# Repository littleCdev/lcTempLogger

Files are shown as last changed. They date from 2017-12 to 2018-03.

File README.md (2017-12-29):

# lcTempLogger
lcTemplogger is a simple ESP8266 temperature-logger using the DS18B22 onewire sensors to feed iot-databases like emoncms / thinkspeak / etc.
You can flash the software onto the ESP8266 without editing the code, setting up the wifi is done via a webinterface.

## Sleep mode
the used ESP8266-01 requires the GPIO 16 wired to RST to wake up from deepsleep mode. if you don't do this the ESP will 
never wake up on itself.
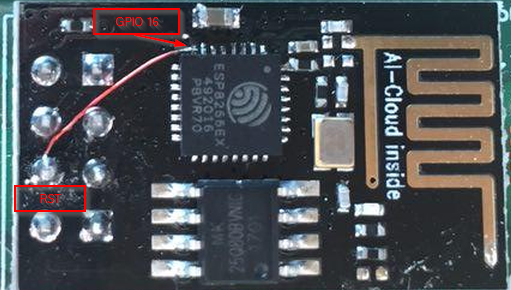
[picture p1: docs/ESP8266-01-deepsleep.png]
ESP8266-01 Deepsleep


## Powersaving
To not drain the batteries too much, the ESP will shutdown after 5 minutes of inactivity in configuration mode, you can simply wake it up again by pressing the reset button.

I suggest to remove the red power-led from the board. This can be done using a soldering iron or just break it out carefully.

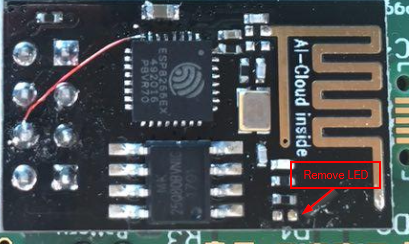
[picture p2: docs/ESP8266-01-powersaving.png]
ESP8266-01 Powersaving ESP8266-01 remove power-led


## Building
Building and flashing is done via the Arduino-IDE

add the ESP to your IDE following this guide 
https://github.com/esp8266/Arduino#installing-with-boards-manager

All other required libraries like onewire and the DS18B22 are included into the sketch. Go to arduino/lcTempLogger/ and open lcTempLogger.ino and hit the uploadbutton

Settings
* Board "Generic ESP8266 Module"
* Flash Mode "DIO"
* Flash Frequency "40MHz"
* CPU Frequency "80MHz"
* Flash Size "1M (512k SPIFFS)"
* Debug port "Disabled"
* Debug Level "None"
* Reset Method "ck"
* Upload Speed "115200"

#### uploading the sketchdata
Use the [esp8266fs-plugin](https://github.com/esp8266/arduino-esp8266fs-plugin) to upload the data into the spiffs.

After including the plugin into the IDE you can simply hit tool->ESP8266 Sketch Data Upload 

## Configuring
If done everything correctly you should be able to find a wifi called "LC-ESP8266-XXXXXXXX",
 connect to it with the password "12345678" (yes, i know it is insecure, but the wifi will be on for configuration only) 
and open 192.168.1.4 in a webbrowser. Select your Network, enter the password and hit "Save" after waiting a bit 
(the ESP is sometimes slow with connecting) until the Wifistatus changes to "connected".
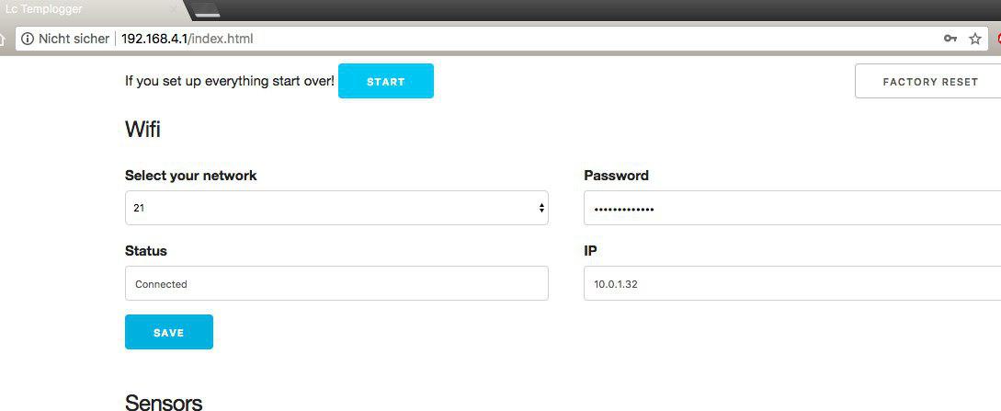
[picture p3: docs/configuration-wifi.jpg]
Wifi configuration

#### API's
Under "API's" you are able to select a preset for emoncms or thinkspeak, just replace your apikey with the placesholder.
I you want to use another API just add the URL, the method (Post or Get) and set the headers and Postdata.
Hit save and try making a testcall under "Test API", you will see the response in the textbox below the testbutton.

If everything works go to the top of the page and hit "Start" to set the ESP to deepsleep.

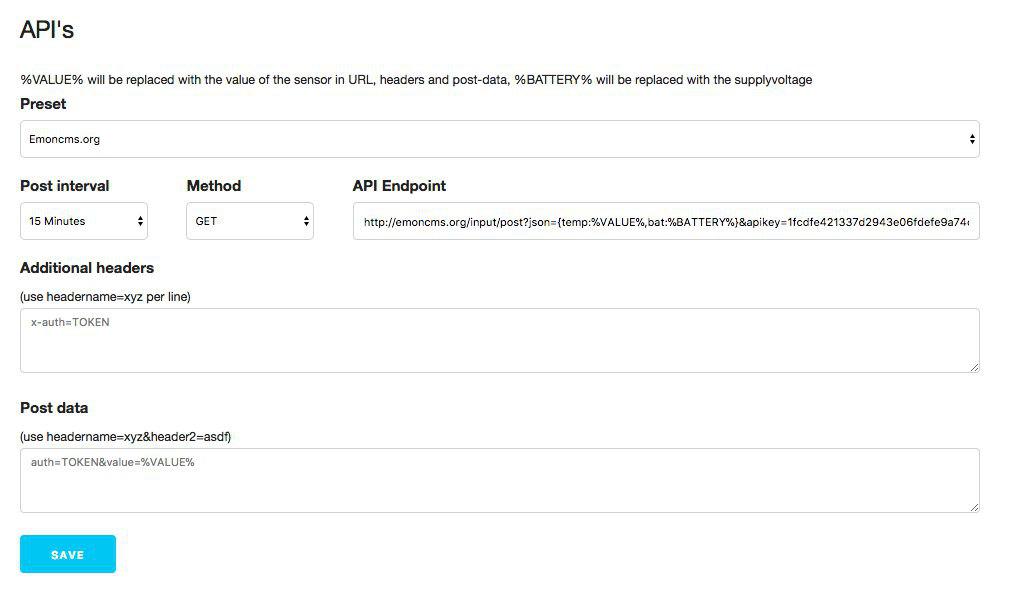
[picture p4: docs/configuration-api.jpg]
API configuration

#### Aborting deepsleep
if you want to wake up the ESP to change settings like API, wifi or whatever press the reset-button, after that you have 2 seconds 
to press the "Set" button once and the ESP will wake up with the accesspoint enabled for configuring. (You need to start the deepsleep again via the webinterface)

## Boards
the board is designed to work with normal AAA-batteries or a 3.7V Lipo including a simple charging circuit using the TP4056 and a MCP1700 as voltageregulator.
You can find the eagle-files in eagle/ (eagle version 7.5)
Boards can be easily ordered at [aisler.net](https://aisler.net/littleCdev/my-project-repository/esp8266-templogger)

Example boards from aisler, left: AAA-battery powered, right using a 3.7V 500mAh lipo battery with charger
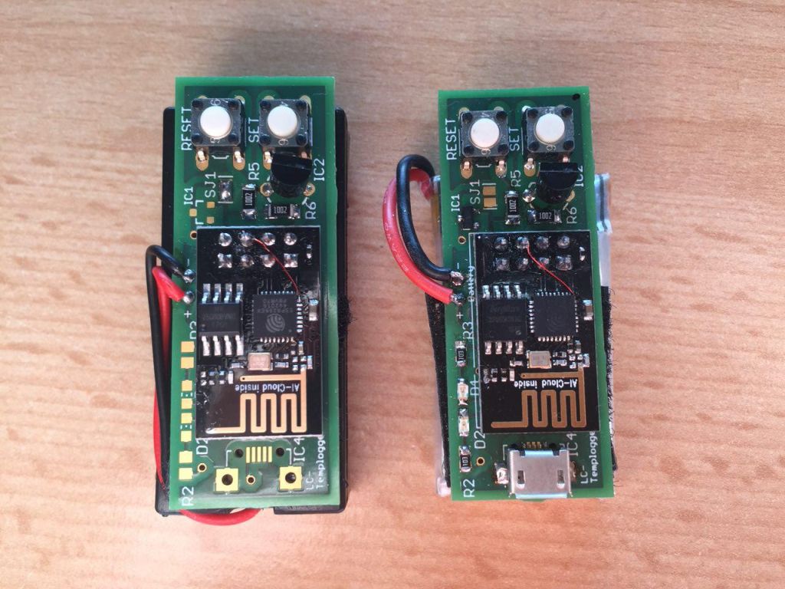
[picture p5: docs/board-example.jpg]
Example boards from aisler


>For AAA-battery powered boards set SJ1 and **don't** place following components 
* IC1 
* IC3
* R1
* R2
* R3
* D1
* D2

# Licence MIT
Copyright 2017 Matthias Böck

Permission is hereby granted, free of charge, to any person obtaining a copy of this software and associated documentation files (the "Software"), to deal in the Software without restriction, including without limitation the rights to use, copy, modify, merge, publish, distribute, sublicense, and/or sell copies of the Software, and to permit persons to whom the Software is furnished to do so, subject to the following conditions:

The above copyright notice and this permission notice shall be included in all copies or substantial portions of the Software.

THE SOFTWARE IS PROVIDED "AS IS", WITHOUT WARRANTY OF ANY KIND, EXPRESS OR IMPLIED, INCLUDING BUT NOT LIMITED TO THE WARRANTIES OF MERCHANTABILITY, FITNESS FOR A PARTICULAR PURPOSE AND NONINFRINGEMENT. IN NO EVENT SHALL THE AUTHORS OR COPYRIGHT HOLDERS BE LIABLE FOR ANY CLAIM, DAMAGES OR OTHER LIABILITY, WHETHER IN AN ACTION OF CONTRACT, TORT OR OTHERWISE, ARISING FROM, OUT OF OR IN CONNECTION WITH THE SOFTWARE OR THE USE OR OTHER DEALINGS IN THE SOFTWARE.

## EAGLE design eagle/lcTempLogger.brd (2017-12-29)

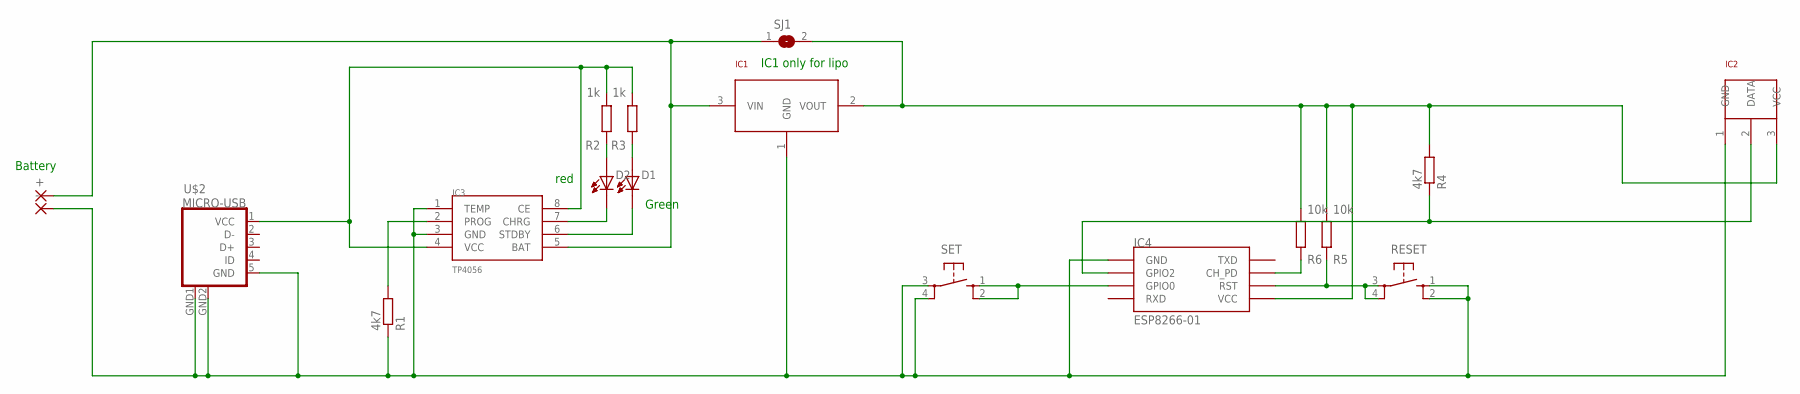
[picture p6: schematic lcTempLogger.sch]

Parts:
+: 1,6/0,8
-: 1,6/0,8
D1, D2: LED-0805; CHIPLED_0805
IC1: MCP1700; SOT-23
IC2: DS18B20TO-92; TO-92
IC3: TP4056; SOP-8
IC4: ESP8266-01; ESP01
R1, R4: 4k7; R1206
R2, R3: 1k; R0805
R5, R6: 10k; R1206
RESET: 10-XX; B3F-10XX
SET: 10-XX; B3F-10XX
SJ1: SJ
U$2: MICRO-USB

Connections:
3V: IC1.2 (VOUT), IC2.3 (VCC), IC4.VCC, R4.2, R5.2, R6.2, SJ1.2
5V_USB: IC3.4 (VCC), IC3.8 (CE), R2.2, R3.2, U$2.1 (VCC)
GND: -.1, IC1.1 (GND), IC2.1 (GND), IC3.1 (TEMP), IC3.3 (GND), IC4.GND, R1.1, RESET.1, RESET.2, SET.3, SET.4, U$2.5 (GND), U$2.GND1 (GND), U$2.GND2 (GND)
unnamed: D2.C (K), IC3.7 (CHRG)
unnamed: IC2.2 (DATA), IC4.GPIO2, R4.1
unnamed: +.1, IC1.3 (VIN), IC3.5 (BAT), SJ1.1
unnamed: IC4.GPIO0, SET.1, SET.2
unnamed: D1.C (K), IC3.6 (STDBY)
unnamed: IC3.2 (PROG), R1.2
unnamed: D2.A, R2.1
unnamed: D1.A, R3.1
unnamed: IC4.RST, R5.1, RESET.3, RESET.4
unnamed: IC4.CH_PD, R6.1

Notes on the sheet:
Battery
IC1 only for lipo
Green
red

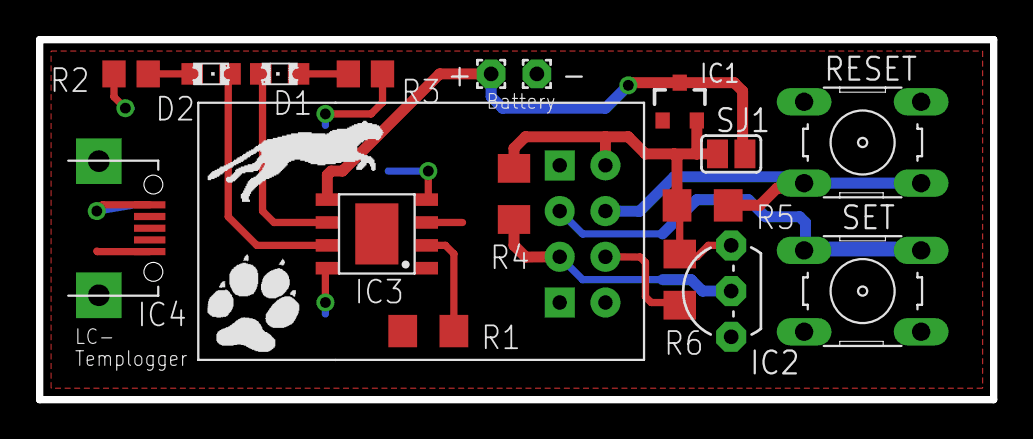
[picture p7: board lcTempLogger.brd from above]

Board: 2 copper layers, 53.0 x 20.0 mm, 20 parts (0 on the bottom side), 13 nets.

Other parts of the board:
U$1: LOGO-21-SMALL-PAW
U$3: LOGO-21-MIDDLE-CHEETAH

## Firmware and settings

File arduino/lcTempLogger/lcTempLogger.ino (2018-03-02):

#include <ESP8266WiFi.h>
#include <WiFiClient.h>
#include <ESP8266WebServer.h>
#include <ESP8266mDNS.h>
#include <ESP8266HTTPClient.h>
#include <DNSServer.h>
#include "OneWire.h"
#include "DallasTemperature.h"
#include "FS.h"

#define HOSTNAME            "ESP8622"
#define APDEFAULTNAME       "LC-ESP8266"    // mac will be added to the end
#define APDEFAULTPW         "12345678"
#define ONE_WIRE_BUS        2               // GPIO
#define INACIVITY_RESET     g_ulInactivTime = millis();Serial.println("reset inactivity");
/*
 * https://thingspeak.com/
 * https://github.com/nothans/ESP8266/blob/master/examples/A0_to_ThingSpeak.ino
 * 
 * https://io.adafruit.com/
 *
 * https://emoncms.org/
 */

/*
 * Prototypes
 */
void sendFile(String sFile = "");
void goToSleep();
void shutdown();
void factoryReset();
bool saveStringToFile(String sContent,String sName);
String readStringFromFile(String sName);
void getDefaultApName(char *sString);
void saveApiSettings();
void getApiSettings();
String saveWifiSettings();
void handleNotFound();
void getNetworkStatus();
void setupWebserver();
void checkForDeepSleep();

/*
 * Globals
 */
// IP-Addresses for accesspoint
IPAddress g_apIP(192, 168, 4, 1);
IPAddress g_netMsk(255, 255, 255, 0);

// Web-server
ESP8266WebServer server(80);

// DNS-server
const byte DNS_PORT = 53;
DNSServer dnsServer;

// 1wire sensor (DS18B20)
OneWire oneWire(ONE_WIRE_BUS);
DallasTemperature sensors(&oneWire);

// measure supplyvoltage
ADC_MODE(ADC_VCC);

// timeout for wifi-connect
unsigned long g_ulStartTime;
unsigned long g_ulInactivTime;
// 
int g_bTryConnect = false;
int g_bConnectCanel = false;
// don't send Message to client
int g_bDeepSleep = false;
void goToSleep(){
  if(!g_bDeepSleep){
    // don't write the file every time
    saveStringToFile("1","deepsleep");
    server.send(200,"text/json","see ya!");
  }
  
  Serial.println("good night!");
  
  String sSleepTime = readStringFromFile("api.interval");
  int iSleepTime = sSleepTime.toInt();
  // 1000000 == 1s 
  ESP.deepSleep(1000000*60*iSleepTime, WAKE_RF_DEFAULT);
  delay(100);
}

void shutdown(){
  Serial.println("shutdown");
  ESP.deepSleep(999999999*999999999*999999999U, WAKE_RF_DEFAULT);
  delay(100);
}


void factoryReset(){
  SPIFFS.remove("api.method");
  SPIFFS.remove("api.endpoint");
  SPIFFS.remove("api.headers");
  SPIFFS.remove("api.post");
  SPIFFS.remove("api.interval");
  
  SPIFFS.remove("wifi.name");
  SPIFFS.remove("wifi.pw");
  SPIFFS.remove("deepsleep");

   ESP.eraseConfig();
   ESP.restart();  
}

bool setApiRequest(){
  String sValue = "";

  if(WiFi.status() != WL_CONNECTED){
    if(!g_bDeepSleep)
      server.send(200,"text/plain","wifi not connected!");

    Serial.println("wifi not connected!");
    return false;
  }

  // 85°C == Failture
  while(sValue == "" || sValue.startsWith("85.0")){
    sensors.requestTemperatures();
    delay(10);
    sValue = sensors.getTempCByIndex(0);
  }
  float fVcc=ESP.getVcc()/1024.00f;
  String sVcc = String(fVcc);
  
  String sEndPoint = readStringFromFile("api.endpoint");

  String sMethod = readStringFromFile("api.method");

  sMethod.toLowerCase();
  
  sEndPoint.replace("%VALUE%",sValue);
  sEndPoint.replace("%BATTERY%",sVcc);
  Serial.println("endpoint: "+sEndPoint);
  
  
  HTTPClient http;
  http.begin(sEndPoint);

  // add headers
  File fHeaders = SPIFFS.open("api.headers","r");
  if(fHeaders){
    String sLine = "";
    while(sLine = fHeaders.readStringUntil('\n')){
      
      if(sLine.length() == 0)
        break;

      sLine.replace("%VALUE%",sValue);
      sLine.replace("%BATTERY%",sVcc);
      Serial.println("Read line from api.headers: "+sLine);

      for (int i = 0; i < sLine.length(); i++) {
        if (sLine.substring(i, i+1) == "=") {
          String sKey = sLine.substring(0, i);
          String sValue = sLine.substring(i+1);

          Serial.println("Found header: "+sKey+" - "+sValue);
          http.addHeader(sKey,sValue);
          i=sLine.length();
        }
      }
    }
  }else{
    Serial.println("no headers to add");
  }

  
  int iHttpCode = -1;
  if(sMethod == "post"){
    
    http.addHeader("Content-Type", "application/x-www-form-urlencoded");
    char acPayload[200] = {};
    String sPayload = "";
    File fPostData = SPIFFS.open("api.post","r");
    if(!fPostData){
      Serial.println("failed to open api.method");
    }else{
          while (fPostData.available()){
            sPayload += char(fPostData.read());
          }
          fPostData.close();
          
          sPayload.replace("%VALUE%",sValue);
          sPayload.replace("%BATTERY%",sVcc);
          
  }
    
    Serial.println("POST");
//    iHttpCode = http.POST((uint8_t*)acPayload,sizeof(acPayload));
    iHttpCode = http.POST(sPayload);
  }else{
    Serial.println("GET");
    iHttpCode = http.GET();
  }
  
  Serial.println("http-code: ");
  Serial.println(iHttpCode);

  if(!g_bDeepSleep)
    server.send(200,"text/plain",http.getString());
  
  http.end();
  return true;
}

bool saveStringToFile(String sContent,String sName){
  File fName = SPIFFS.open(sName,"w");
  if(!fName){
    Serial.println("failed to open "+sName);
     return false;
  }
  fName.print(sContent);
  fName.close();
  return true;
}
String readStringFromFile(String sName){
  if(!SPIFFS.exists(sName)){
    return "";
  }
  
  File fFile = SPIFFS.open(sName,"r");
  if(!fFile){
    Serial.println("failed to open "+sName);
    return "";
  }

  String sRead = fFile.readStringUntil('\n');
  fFile.close();

  return sRead;
}
void getDefaultApName(char *sString){
  byte mac[6] = {0};
  WiFi.macAddress(mac);
  snprintf(sString,100,"%s-%02x%02x%02x%02x%02x%02x",APDEFAULTNAME,mac[0],mac[1],mac[2],mac[3],mac[4],mac[5]);
}

void saveApiSettings(){
  for (uint8_t i=0; i<server.args(); i++){
    if(server.argName(i) == "ApiMethod"){
      saveStringToFile(server.arg(i),"api.method");
    }
    if(server.argName(i) == "ApiEndpoint"){
      saveStringToFile(server.arg(i),"api.endpoint");
    }
    if(server.argName(i) == "ApiHeaders"){
      saveStringToFile(server.arg(i),"api.headers");
    }
    if(server.argName(i) == "ApiPost"){
      saveStringToFile(server.arg(i),"api.post");
    }
    if(server.argName(i) == "ApiInterval"){
      saveStringToFile(server.arg(i),"api.interval");
    }
  }
}

void getApiSettings(){
  String sMessage = "{\"method\":\"";
  sMessage += readStringFromFile("api.method");
  sMessage += "\",\"endpoint\":\"";
  sMessage += readStringFromFile("api.endpoint");
  sMessage += "\",\"headers\":\"";
  sMessage += readStringFromFile("api.headers");
  sMessage += "\",\"post\":\"";
  sMessage += readStringFromFile("api.post");
  sMessage += "\",\"interval\":\"";
  sMessage += readStringFromFile("api.interval");
  sMessage += "\"}";
  server.send(200,"text/json",sMessage);
}

void WifiTryConnect(){
  String sPasswd = "";
  char charBufsPasswd[50];
  String sWifiName = "";
  char charBufsWifiName[50];

  sWifiName = readStringFromFile("wifi.name");
  sPasswd = readStringFromFile("wifi.pw");
  
  Serial.println("got networkname: "+sWifiName+" and password: "+sPasswd);
  // convert "String" into char[]... i hate c++
  sPasswd.toCharArray(charBufsPasswd, 50);
  sWifiName.toCharArray(charBufsWifiName, 50);

  WiFi.begin(charBufsWifiName,charBufsPasswd);
  g_bConnectCanel = false;
}

String saveWifiSettings(){
  String sPasswd = "";
  String sName = "";
  
  for (uint8_t i=0; i<server.args(); i++){
    if(server.argName(i) == "WifiName"){
      sName = server.arg(i);
    }
   if(server.argName(i) == "WifiPass"){
      sPasswd = server.arg(i);
    }
  }

  if(sName.length() == 0){
    return "Wifiname can't be empty!";
  }

  // save settings to files
  if(!saveStringToFile(sName,"wifi.name")){
     Serial.println("failed to save wifi.name");
     return"failed to save wifi.name" ;
  }
  Serial.println("saved wifi.name");
  
  if(!saveStringToFile(sPasswd,"wifi.pw")){
     Serial.print("failed to save wifi.pw");
     return"failed to save wifi.pw" ;
  }
  Serial.println("saved wifi.pw");

  g_bTryConnect = 1;
  
  return "Saved";
}


void handleNotFound(){
  INACIVITY_RESET

  if(SPIFFS.exists(server.uri())){
    sendFile();
    return;
  }
  if(server.uri()=="/"){
    sendFile("/index.html");
    return;
  }
    
  String message = "File Not Found\n\n";
  message += "URI: ";
  message += server.uri();
  message += "\nMethod: ";
  message += (server.method() == HTTP_GET)?"GET":"POST";
  message += "\nArguments: ";
  message += server.args();
  message += "\n";
  for (uint8_t i=0; i<server.args(); i++){
    message += " " + server.argName(i) + ": " + server.arg(i) + "\n";
  }
  server.send(404, "text/plain", message);
}

void sendFile(String sFile){
  String sFileToSend = sFile;
  if(sFile.length() == 0)
    sFileToSend = server.uri();
    
  Serial.println("trying to send file: "+sFileToSend);
  File f = SPIFFS.open(sFileToSend,"r");
  if(!f){
    Serial.println("failed to open "+sFileToSend);
    return;
  }

  if(sFileToSend.endsWith("html")){
    server.streamFile(f,"text/html");     
  }else if(sFileToSend.endsWith("css")){
    server.streamFile(f,"text/css");    
  }else if(sFileToSend.endsWith("js")){
    server.streamFile(f,"text/javascript");    
  }
  f.close();
}
void getNetworkStatus(){
  IPAddress ip = WiFi.localIP();
  String sMessage = "{\"state\":\"";

  switch(WiFi.status())
  {
    case WL_NO_SHIELD: sMessage+= "No Wifi shiled";  break;
    case WL_IDLE_STATUS: sMessage+= "Idle";  break;
    case WL_NO_SSID_AVAIL: sMessage+= "SSID not available";  break;
    case WL_SCAN_COMPLETED: sMessage+= "Scan done";  break;
    case WL_CONNECTED: sMessage+= "Connected";  break;
    case WL_CONNECT_FAILED: sMessage+= "Connection failed";  break;
    case WL_CONNECTION_LOST: sMessage+= "Connected lost";  break;
    case WL_DISCONNECTED: sMessage+= "Not connected";  break;
  }
  sMessage+="\",\"ip\":\"";
  for(int i=0;i<4;i++){
    sMessage+=ip[i];
    if(i<3)
      sMessage+="."; 
  }
  sMessage+="\"}";
  server.send(200,"text/json",sMessage);
}
void getSensor(){
  String sMessage = "{\"sensor\":\"DS18B20\",\"value\":\"";
  float fVcc=ESP.getVcc()/1024.00f;

  sensors.requestTemperatures(); // Send the command to get temperatures
  sMessage += sensors.getTempCByIndex(0);
  sMessage += "°C\",\"battery\":\"";
  sMessage += String(fVcc)+"V";
  sMessage += "\"}";
  server.send(200,"text/plain",sMessage);
}

void getNetworks(){
  Serial.println("scan start");
  int n = WiFi.scanNetworks();
  Serial.println("scan done");
  String sMessage = "";
  for(int i=0;i<n;i++){
    sMessage += WiFi.SSID(i) +"\n";
  }
  server.send(200,"text/plain",sMessage);
}
void setupWebserver(){
  
  server.on("/factoryReset", factoryReset);
  server.on("/goToSleep", goToSleep);
  server.on("/setApiRequest", setApiRequest);
  
  server.on("/getApiSettings", getApiSettings);
  server.on("/saveApiSettings", saveApiSettings);
  
  server.on("/saveWifiSettings", saveWifiSettings);
  server.on("/WifiTryConnect", WifiTryConnect);
  server.on("/getNetworkStatus", getNetworkStatus);
  server.on("/getNetworks", getNetworks);
  server.on("/getSensor", getSensor);
  
//  server.on("/index.html",sendFile);
  
  server.onNotFound(handleNotFound);
  server.begin();
}

void checkForDeepSleep(){
  String sDeepSleep = readStringFromFile("deepsleep");

  if(!sDeepSleep.startsWith("1"))
    return;

  Serial.println("deepSleep active");

  // wait 2seconds for a buttonpress to reset from deepsleep
  for(int i=0;i<200;i++){
    delay(10);
    if(digitalRead(0) == 0){
      Serial.println("Abroting deepsleep");
      SPIFFS.remove("deepsleep");
      return;
    }
  }
  
  g_bDeepSleep = true;
  
  WiFi.hostname(HOSTNAME);
  WiFi.mode(WIFI_STA);
  WifiTryConnect();
  int i=0;
  while (WiFi.status() != WL_CONNECTED) {
    i++;
    Serial.println(WiFi.status());
    delay(1000);
    if(i>= 30){ // abrot after ~30s
      Serial.println("Abroting connect");
      goToSleep();
    }
  }
  Serial.println("connected!");
  setApiRequest();
  goToSleep();
}

void setup(void){
  Serial.begin(115200);
//  Serial.setDebugOutput(true);
  g_ulStartTime = millis();
  SPIFFS.begin();
  checkForDeepSleep();
  
  INACIVITY_RESET
  setupWebserver();

  // setup accesspoint
  WiFi.hostname(HOSTNAME);
  WiFi.mode(WIFI_AP_STA);
  WiFi.softAPConfig(g_apIP, g_apIP, g_netMsk);
  char sAPName[100] = "";
  getDefaultApName(sAPName);
  WiFi.softAP(sAPName, APDEFAULTPW, 11, false);

  // start DNS server
  dnsServer.start(DNS_PORT, "*", g_apIP);

  if (MDNS.begin(HOSTNAME)) {
    Serial.println("MDNS responder started");
  }
}


void loop(void){
  server.handleClient();
  dnsServer.processNextRequest();
  if(g_bTryConnect == 1){
      INACIVITY_RESET
      g_bTryConnect = 0;
      WifiTryConnect();
  }

  // disconnect wifi after 20s of trying to connect
  // trying to connect blocks the webserver...
  if(WiFi.status() != WL_CONNECTED && g_bConnectCanel != true){ 
    if((millis() - g_ulStartTime) >= 20000){
      Serial.println("abroting connect..");
      WiFi.disconnect();
      WiFi.mode(WIFI_AP);
      g_bConnectCanel = true;
    }
  }else{
    g_ulStartTime = millis();
  }

  // "shutdown" after 5minutes of inactivity
  if((millis() - g_ulInactivTime) >= 5*60*1000){
    shutdown();
  }  
}
